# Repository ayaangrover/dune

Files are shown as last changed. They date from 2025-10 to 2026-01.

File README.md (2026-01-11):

# dune
a wireless low profile hotswap split keyboard

## What it is
Dune is a low profile hotswap wireless split keyboard with ZMK support. 

## Why I made it
I made it because I want to do my homework in my notebook but also be able to type and use my mouse. this way i can place my notebook between the two halves of my keyboard.

## Models
Case models are in /Case, case + pcb and just pcb models are both in /Dune.

## Images





CleanShot 2025-12-22 at 09 49 57@2x

CleanShot 2025-12-22 at 09 50 12@2x

CleanShot 2025-12-22 at 09 50 39@2x

CleanShot 2025-12-22 at 10 57 10@2x

CleanShot 2025-12-22 at 10 56 57@2x

CleanShot 2025-12-22 at 10 58 08@2x

## Bom

I'm printing [these](https://makerworld.com/en/models/2011079-low-profile-choc-v2-17mm-keycap?from=search#profileId-2166451) keycaps for the keyboard.

| Item | Description | Cost (USD) | Link |
|---|---|---|---|
| Switches | Kailh Choc Round Brown 45g (Low-Profile Tactile) | $20.18 | https://mechanicalkeyboards.com/products/kailh-choc-round-brown-45g-low-profile-tactile?variant=50919348699436 |
| Keycaps | 3D printed | $0.00 | https://makerworld.com/en/models/2011079-low-profile-choc-v2-17mm-keycap?from=search#profileId-2166451 |
| Sockets | Kailh Choc sockets | $8.38 | https://www.aliexpress.us/item/3256806931242093.html |
| MCU | nRF52840 | $8.08 | https://www.aliexpress.us/item/3256805848952479.html |
| Batteries | Li-Po batteries | $8.84 | https://www.aliexpress.us/item/3256807087483508.html |
| PCB | Custom PCB fabrication | $57.58 | https://jlcpcb.com/ |
| **Total** |  | **$103.06(tax)** |  |

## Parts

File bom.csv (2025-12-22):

Item | Description | Amount | Cost (USD) | Link
Switches | Kailh Choc Round Brown 45g (Low-Profile Tactile) | 1 | 20.18 | https://mechanicalkeyboards.com/products/kailh-choc-round-brown-45g-low-profile-tactile?variant=50919348699436
Keycaps | 3D printed | 1 | 0.00 | https://makerworld.com/en/models/2011079-low-profile-choc-v2-17mm-keycap?from=search
Sockets | Kailh Choc sockets | 1 | 8.38 | https://www.aliexpress.us/item/3256806931242093.html
MCU | nRF52840 | 1 | 8.08 | https://www.aliexpress.us/item/3256805848952479.html
Batteries | Li-Po batteries | 1 | 4.16 | https://www.aliexpress.us/item/3256807087483508.html
PCB | Custom PCB fabrication | 1 | 57.58 | https://jlcpcb.com/
Total |  | 1 | 100.25

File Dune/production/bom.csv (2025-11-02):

Designator | Footprint | Quantity | Value | LCSC Part #
D1, D10, D11, D12, D13, D14, D15, D16, D17, D18, D19, D2, D20, D21, D22, D23, D24, D25, D26, D27, D28, D29, D3, D30, D31, D32, D33, D34, D35, D36, D37, D38, D39, D4, D40, D41, D42, D5, D6, D7, D8, D9 | Diode_SOD-123 | 42 | Diode
S1, S10, S11, S12, S13, S14, S15, S16, S17, S18, S19, S2, S20, S21, S22, S23, S24, S25, S26, S27, S28, S29, S3, S30, S31, S32, S33, S34, S35, S36, S37, S38, S39, S4, S40, S41, S42, S5, S6, S7, S8, S9 | Hotswap_Choc_V2_1.00u | 42 | Keyswitch
SW1, SW2 | SW-SMD_MK-12C03-G015 | 2 | MK-12C03-G015 | C2890358
U3, U4 | CONN-TH_S2B-PH-K-S-LF-SN | 2 | S2B-PH-K-S(LF)(SN) | C173752

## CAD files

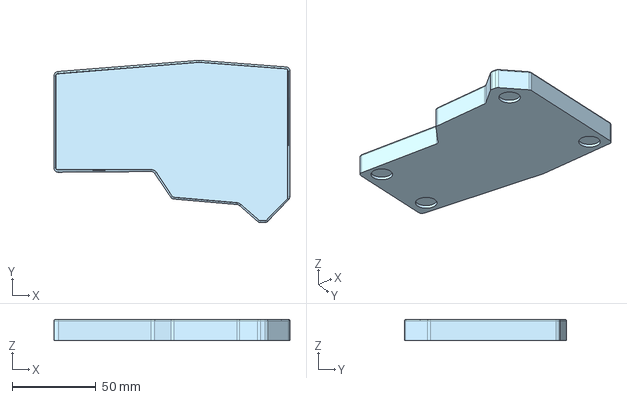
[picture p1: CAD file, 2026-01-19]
CAD/case_left.step
140.9 x 96.9 x 12.7 mm

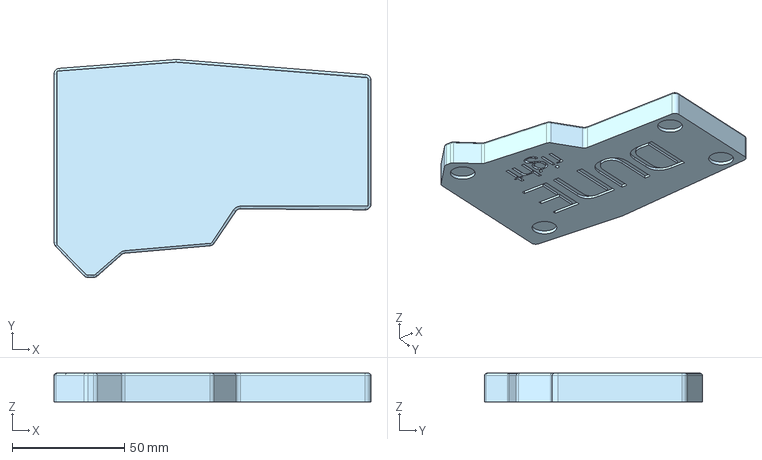
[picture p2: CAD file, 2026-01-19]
CAD/case_right.step
140.9 x 96.9 x 12.7 mm

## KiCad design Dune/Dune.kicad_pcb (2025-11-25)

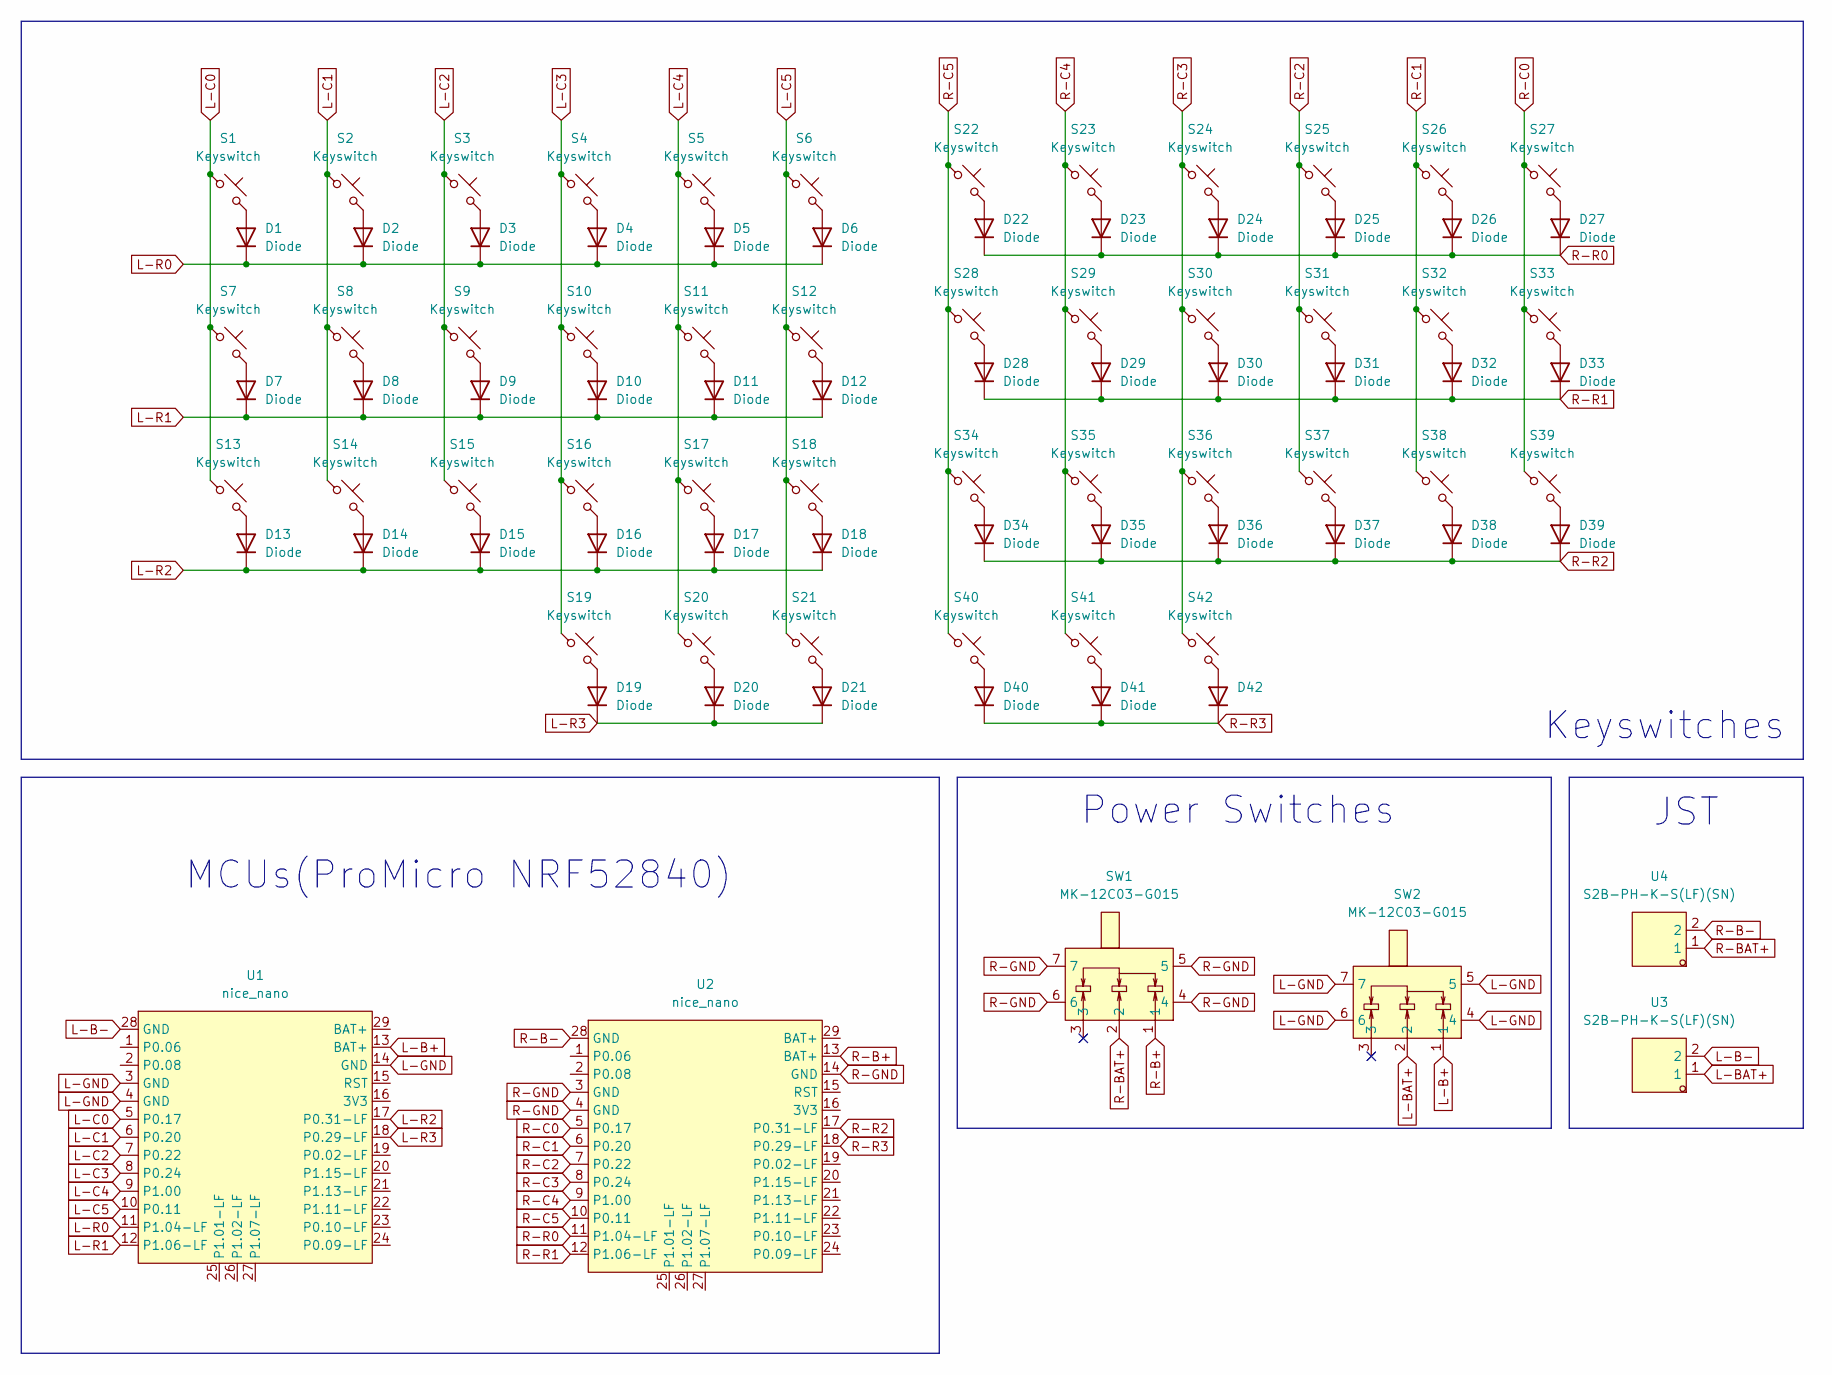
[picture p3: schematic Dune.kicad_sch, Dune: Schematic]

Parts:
D1, D2, D3, D4, D5, D6, D7, D8, D9, D10, D11, D12, D13, D14, D15, D16, D17, D18, D19, D20, D21, D22, D23, D24, D25, D26, D27, D28, D29, D30, D31, D32, D33, D34, D35, D36, D37, D38, D39, D40, D41, D42: Diode; Diode_SOD-123
S1, S2, S3, S4, S5, S6, S7, S8, S9, S10, S11, S12, S13, S14, S15, S16, S17, S18, S19, S20, S21, S22, S23, S24, S25, S26, S27, S28, S29, S30, S31, S32, S33, S34, S35, S36, S37, S38, S39, S40, S41, S42: Keyswitch; Hotswap_Choc_V2_1.00u
SW1, SW2: MK-12C03-G015; SW-SMD_MK-12C03-G015; LCSC Part C2890358
U1, U2: nice_nano; SuperMini NRF52840
U3, U4: S2B-PH-K-S(LF)(SN); CONN-TH_S2B-PH-K-S-LF-SN; LCSC Part C173752

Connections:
L-B+: SW2.1, U1.13 (BAT+)
L-B-: U1.28 (GND), U3.2
L-BAT+: SW2.2, U3.1
L-C0: S1.1, S7.1, S13.1, U1.5 (P0.17)
L-C1: S2.1, S8.1, S14.1, U1.6 (P0.20)
L-C2: S3.1, S9.1, S15.1, U1.7 (P0.22)
L-C3: S4.1, S10.1, S16.1, S19.1, U1.8 (P0.24)
L-C4: S5.1, S11.1, S17.1, S20.1, U1.9 (P1.00)
L-C5: S6.1, S12.1, S18.1, S21.1, U1.10 (P0.11)
L-GND: SW2.4, SW2.5, SW2.6, SW2.7, U1.3 (GND), U1.4 (GND), U1.14 (GND)
L-R0: D1.1 (K), D2.1 (K), D3.1 (K), D4.1 (K), D5.1 (K), D6.1 (K), U1.11 (P1.04-LF)
L-R1: D7.1 (K), D8.1 (K), D9.1 (K), D10.1 (K), D11.1 (K), D12.1 (K), U1.12 (P1.06-LF)
L-R2: D13.1 (K), D14.1 (K), D15.1 (K), D16.1 (K), D17.1 (K), D18.1 (K), U1.17 (P0.31-LF)
L-R3: D19.1 (K), D20.1 (K), D21.1 (K), U1.18 (P0.29-LF)
unnamed: D1.2 (A), S1.2
unnamed: D2.2 (A), S2.2
unnamed: D3.2 (A), S3.2
unnamed: D4.2 (A), S4.2
unnamed: D5.2 (A), S5.2
unnamed: D6.2 (A), S6.2
unnamed: D7.2 (A), S7.2
unnamed: D8.2 (A), S8.2
unnamed: D9.2 (A), S9.2
unnamed: D10.2 (A), S10.2
unnamed: D11.2 (A), S11.2
unnamed: D12.2 (A), S12.2
unnamed: D13.2 (A), S13.2
unnamed: D14.2 (A), S14.2
unnamed: D15.2 (A), S15.2
unnamed: D16.2 (A), S16.2
unnamed: D17.2 (A), S17.2
unnamed: D18.2 (A), S18.2
unnamed: D19.2 (A), S19.2
unnamed: D20.2 (A), S20.2
unnamed: D21.2 (A), S21.2
unnamed: D22.2 (A), S22.2
unnamed: D23.2 (A), S23.2
unnamed: D24.2 (A), S24.2
unnamed: D25.2 (A), S25.2
unnamed: D26.2 (A), S26.2
unnamed: D27.2 (A), S27.2
unnamed: D28.2 (A), S28.2
unnamed: D29.2 (A), S29.2
unnamed: D30.2 (A), S30.2
unnamed: D31.2 (A), S31.2
unnamed: D32.2 (A), S32.2
unnamed: D33.2 (A), S33.2
unnamed: D34.2 (A), S34.2
unnamed: D35.2 (A), S35.2
unnamed: D36.2 (A), S36.2
unnamed: D37.2 (A), S37.2
unnamed: D38.2 (A), S38.2
unnamed: D39.2 (A), S39.2
unnamed: D40.2 (A), S40.2
unnamed: D41.2 (A), S41.2
unnamed: D42.2 (A), S42.2
R-B+: SW1.1, U2.13 (BAT+)
R-B-: U2.28 (GND), U4.2
R-BAT+: SW1.2, U4.1
R-C0: S27.1, S33.1, S39.1, U2.5 (P0.17)
R-C1: S26.1, S32.1, S38.1, U2.6 (P0.20)
R-C2: S25.1, S31.1, S37.1, U2.7 (P0.22)
R-C3: S24.1, S30.1, S36.1, S42.1, U2.8 (P0.24)
R-C4: S23.1, S29.1, S35.1, S41.1, U2.9 (P1.00)
R-C5: S22.1, S28.1, S34.1, S40.1, U2.10 (P0.11)
R-GND: SW1.4, SW1.5, SW1.6, SW1.7, U2.3 (GND), U2.4 (GND), U2.14 (GND)
R-R0: D22.1 (K), D23.1 (K), D24.1 (K), D25.1 (K), D26.1 (K), D27.1 (K), U2.11 (P1.04-LF)
R-R1: D28.1 (K), D29.1 (K), D30.1 (K), D31.1 (K), D32.1 (K), D33.1 (K), U2.12 (P1.06-LF)
R-R2: D34.1 (K), D35.1 (K), D36.1 (K), D37.1 (K), D38.1 (K), D39.1 (K), U2.17 (P0.31-LF)
R-R3: D40.1 (K), D41.1 (K), D42.1 (K), U2.18 (P0.29-LF)

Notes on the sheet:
MCUs(ProMicro NRF52840)
JST
Keyswitches
Power Switches

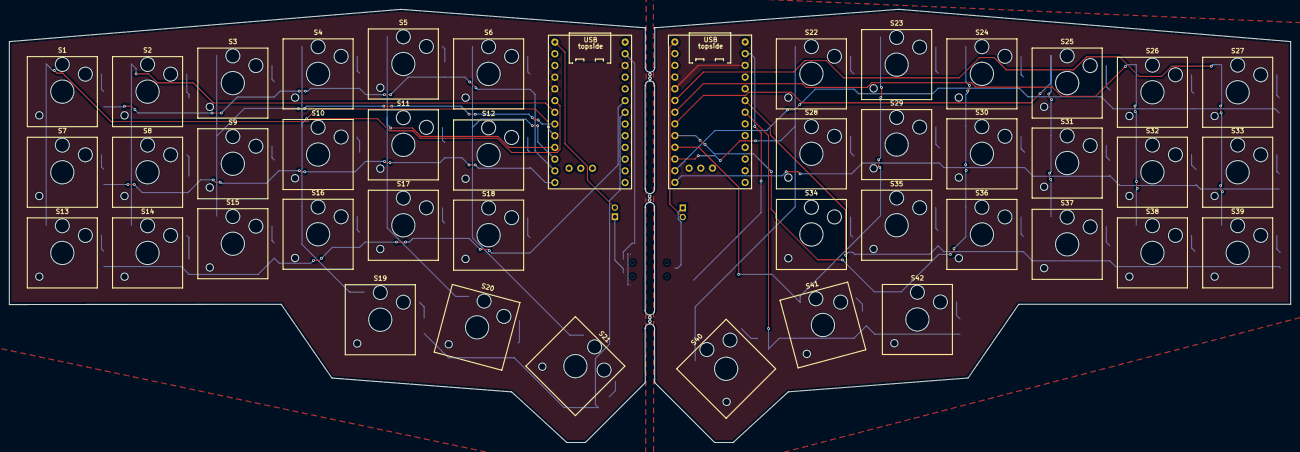
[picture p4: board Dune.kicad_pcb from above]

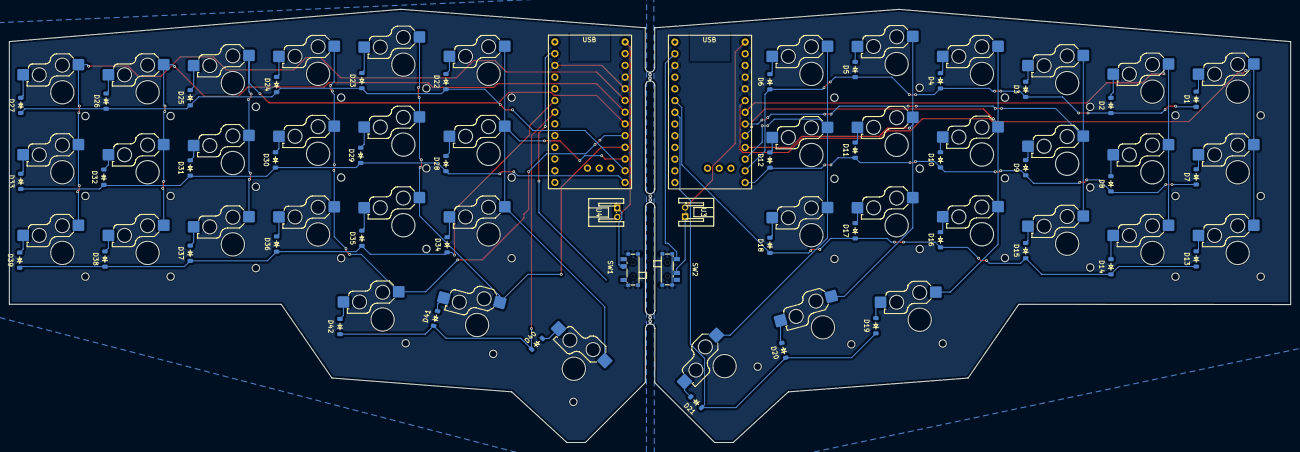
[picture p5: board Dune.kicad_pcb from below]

Board: 2 copper layers, 278.0 x 94.0 mm, 90 parts (46 on the bottom side), 70 nets.

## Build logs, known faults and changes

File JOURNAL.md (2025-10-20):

<!--
  ===================    !!READ THIS NOTICE!!   ====================
  DO NOT edit this file manually. Your changes WILL BE OVERWRITTEN!
  This journal is auto generated and updated by Hack Club Blueprint.
  To edit this file, please edit your journal entries on Blueprint.
  ==================================================================
-->

## 10/3/2025 4 PM - Planned the project + budget  

CleanShot 2025-10-03 at 16.13.06@2x.png

So here's my progress so far - it's a bit over the $100 mark but I'm hoping I can find some discounts or jlc coupons to bring the price down a bit(or even changing my shipping method)

using pcba for the diodes + on/off switch + battery connector

going to go and start the pcb now! using scottokeebs' library  

## 10/3/2025 9 PM - research + schematic  

spent a ton of time doing research to cut down the cost, but i only got a few bucks down. absolute waste of time...

then i spent time trying to find a nice!nano v2 footprint which includes the B+ and B- pins but couldnt. 

so i just did the switches and diodes. will do the mcu + connections once i get a symbol+footprint that work.

CleanShot 2025-10-03 at 21.41.45@2x.png

## 10/4/2025 2 PM - Finished the schematic  

CleanShot 2025-10-04 at 14.14.11.png

finished schematic and dumped all the parts into the pcb editor and sent it to jlc for a price test, got a min of $50 AFTER a $15 discount...so now i'm $12 over the budget. 

anyway, im going to do the layout of the pcb and then routing, and also see where else i can save money  

## 10/4/2025 7 PM - Did the PCB Layout + 3D Models  

CleanShot 2025-10-04 at 19.20.09.png

I FINISHED THE LAYOUTTTT!!! that took way too long but i eventually got smth i like, heavily inspired by the corne but it looks great to me. 

oh i also did all the 3d models, that took a while to position for each one

i put most of the stuff on the back so i can get it pcbaed if it fits in my budget

now i have to do the routing. might redo the layout if needed.

CleanShot 2025-10-04 at 19.48.43.png

## 10/4/2025 10 PM - Routed half of the pcb and made a blueprint-style banner!  



routed the left half of the keyboard!

also made a blueprint style banner thingy(inspired by kieran, followed his instructions to make it!)

i think it looks pretty cool, i imported the .step from kicad to onshape, made a drawing, exported as an svg, and fixed it up in figma. i might add some branding to the front or smth as soon as i get around to making a good branding  

## 10/20/2025 - worked on budgeting + edited pcb  

did research, knocked the price down to $100. covering $15 through my school and printing the keycaps.

took almost an hour of researching and asking to get the 15 accepted through maker club though...on the other hand im finally at $100 so i might get approved, only have the case left now!



also realigned some parts w/ issues in the pcb for a bit, it wasnt symmetrical and didnt match my finger length very well so i restaggered them. that part was pretty fun

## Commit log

2025-11-02 Add Dune project files with LFS support
    [Dune.kicad_pcb, Dune.kicad_sch, bom.csv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]
2025-11-02 Add Dune.stl
    [Dune.stl]
2025-11-25 Add case
    [Dune.kicad_pcb, left.stl, positions.csv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]
2025-12-22 Update Dune project: add new backups, STLs, and .gitignore
    [Dune3.stl, caseAndPCB.stl]
2025-12-22 Remove KiCad temporary files from git
2025-12-22 Create bom.csv with item descriptions and costs
    Added bill of materials with item details and costs.
    [bom.csv]
2025-12-22 Add link to Keycaps in bom.csv
    [bom.csv]
2026-01-19 Update and rename left (1).step to CAD/case_left.step
    [case_left.step]
2026-01-19 Add case_right.step file
    [case_right.step]
